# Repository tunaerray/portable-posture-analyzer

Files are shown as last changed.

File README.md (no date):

# Portable Posture & Balance Analyzer

A wearable device designed to monitor back and shoulder posture in real time, alerting the user via vibration and OLED display when poor posture is detected.

> **Work in Progress**  
> PCB design is complete. Firmware development is ongoing.

## Overview

This project is a health and ergonomics-focused embedded system that tracks posture using an IMU sensor. When poor posture is detected, the device triggers a vibration motor and displays a warning on the OLED screen. The system is built around the MSP430G2553 microcontroller.

## Components

- **MPU6050** - 6-axis IMU sensor (accelerometer + gyroscope)
- **Vibration Motor** - Haptic alert for poor posture
- **OLED Display** - Real-time posture score and warning display
- **HC-05 Bluetooth** - Daily report transmission
- **MSP430G2553** - Main microcontroller

## How It Works

1. MPU6050 raw accelerometer and gyroscope data is read over I2C.
2. Angle calculation is performed using `atan2`.
3. A posture score is computed periodically using Timer_A.
4. If poor posture is detected, the vibration motor is activated.
5. The OLED display shows posture status and warning messages.
6. A daily posture report is sent via Bluetooth to a paired device.

## Project Status

- [x] PCB design complete
- [ ] Firmware development in progress
- [ ] Testing and calibration
- [ ] Enclosure design

## Images

### PCB Front

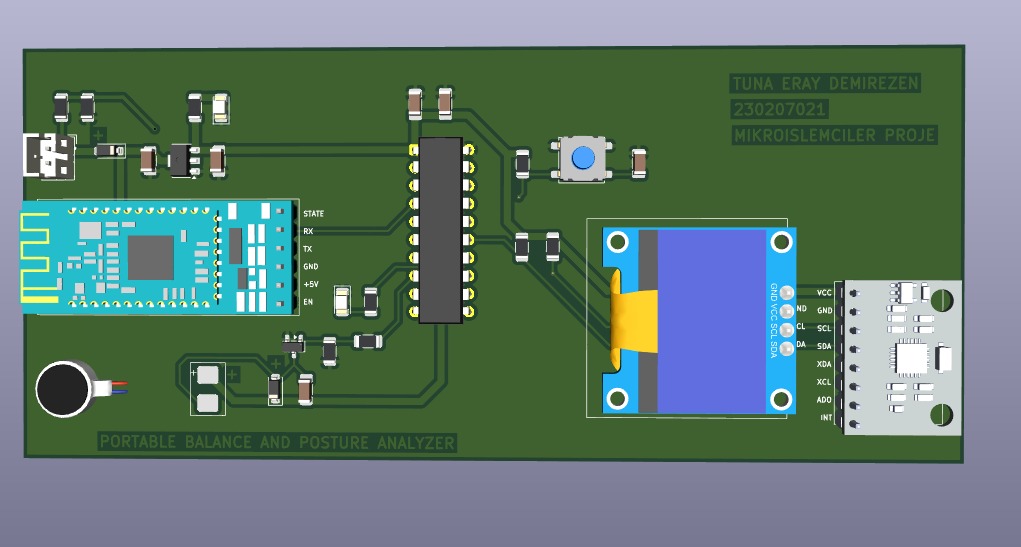
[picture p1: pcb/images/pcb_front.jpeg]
PCB Front


### PCB Back

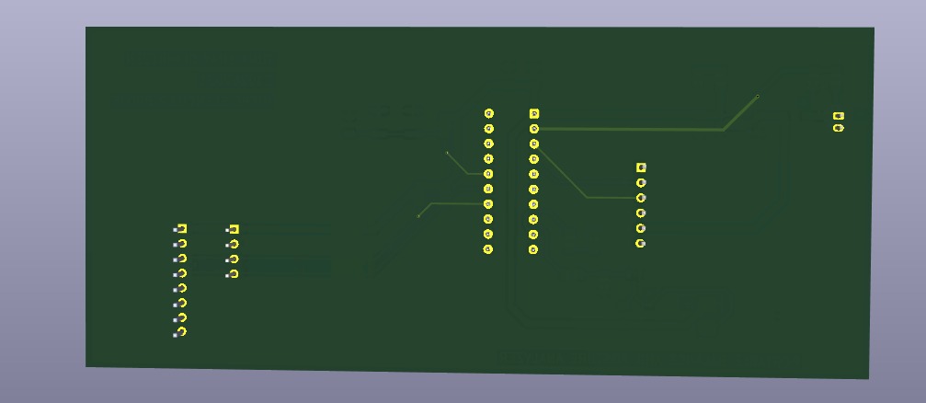
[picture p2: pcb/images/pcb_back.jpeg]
PCB Back


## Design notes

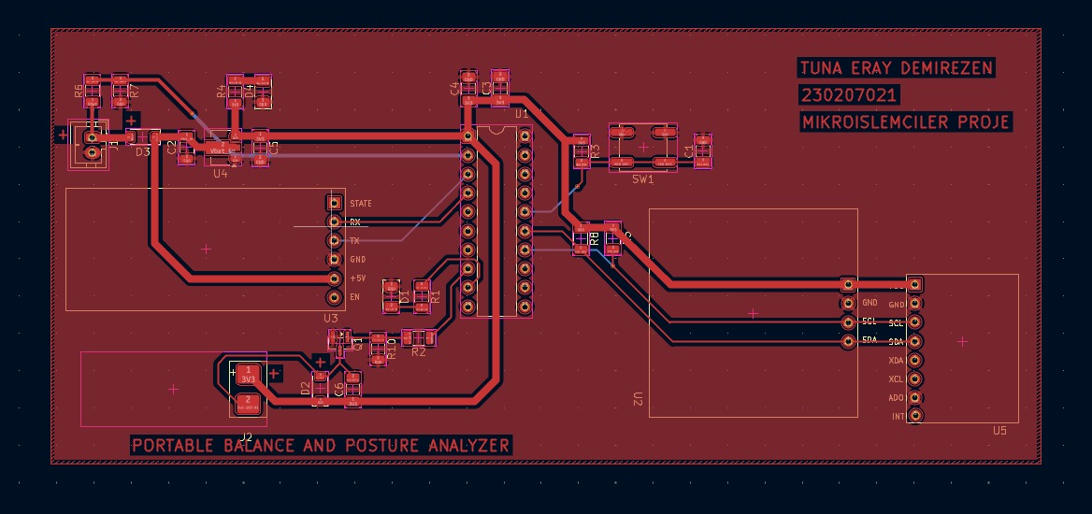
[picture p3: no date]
pcb/images/pcb_layout.jpeg

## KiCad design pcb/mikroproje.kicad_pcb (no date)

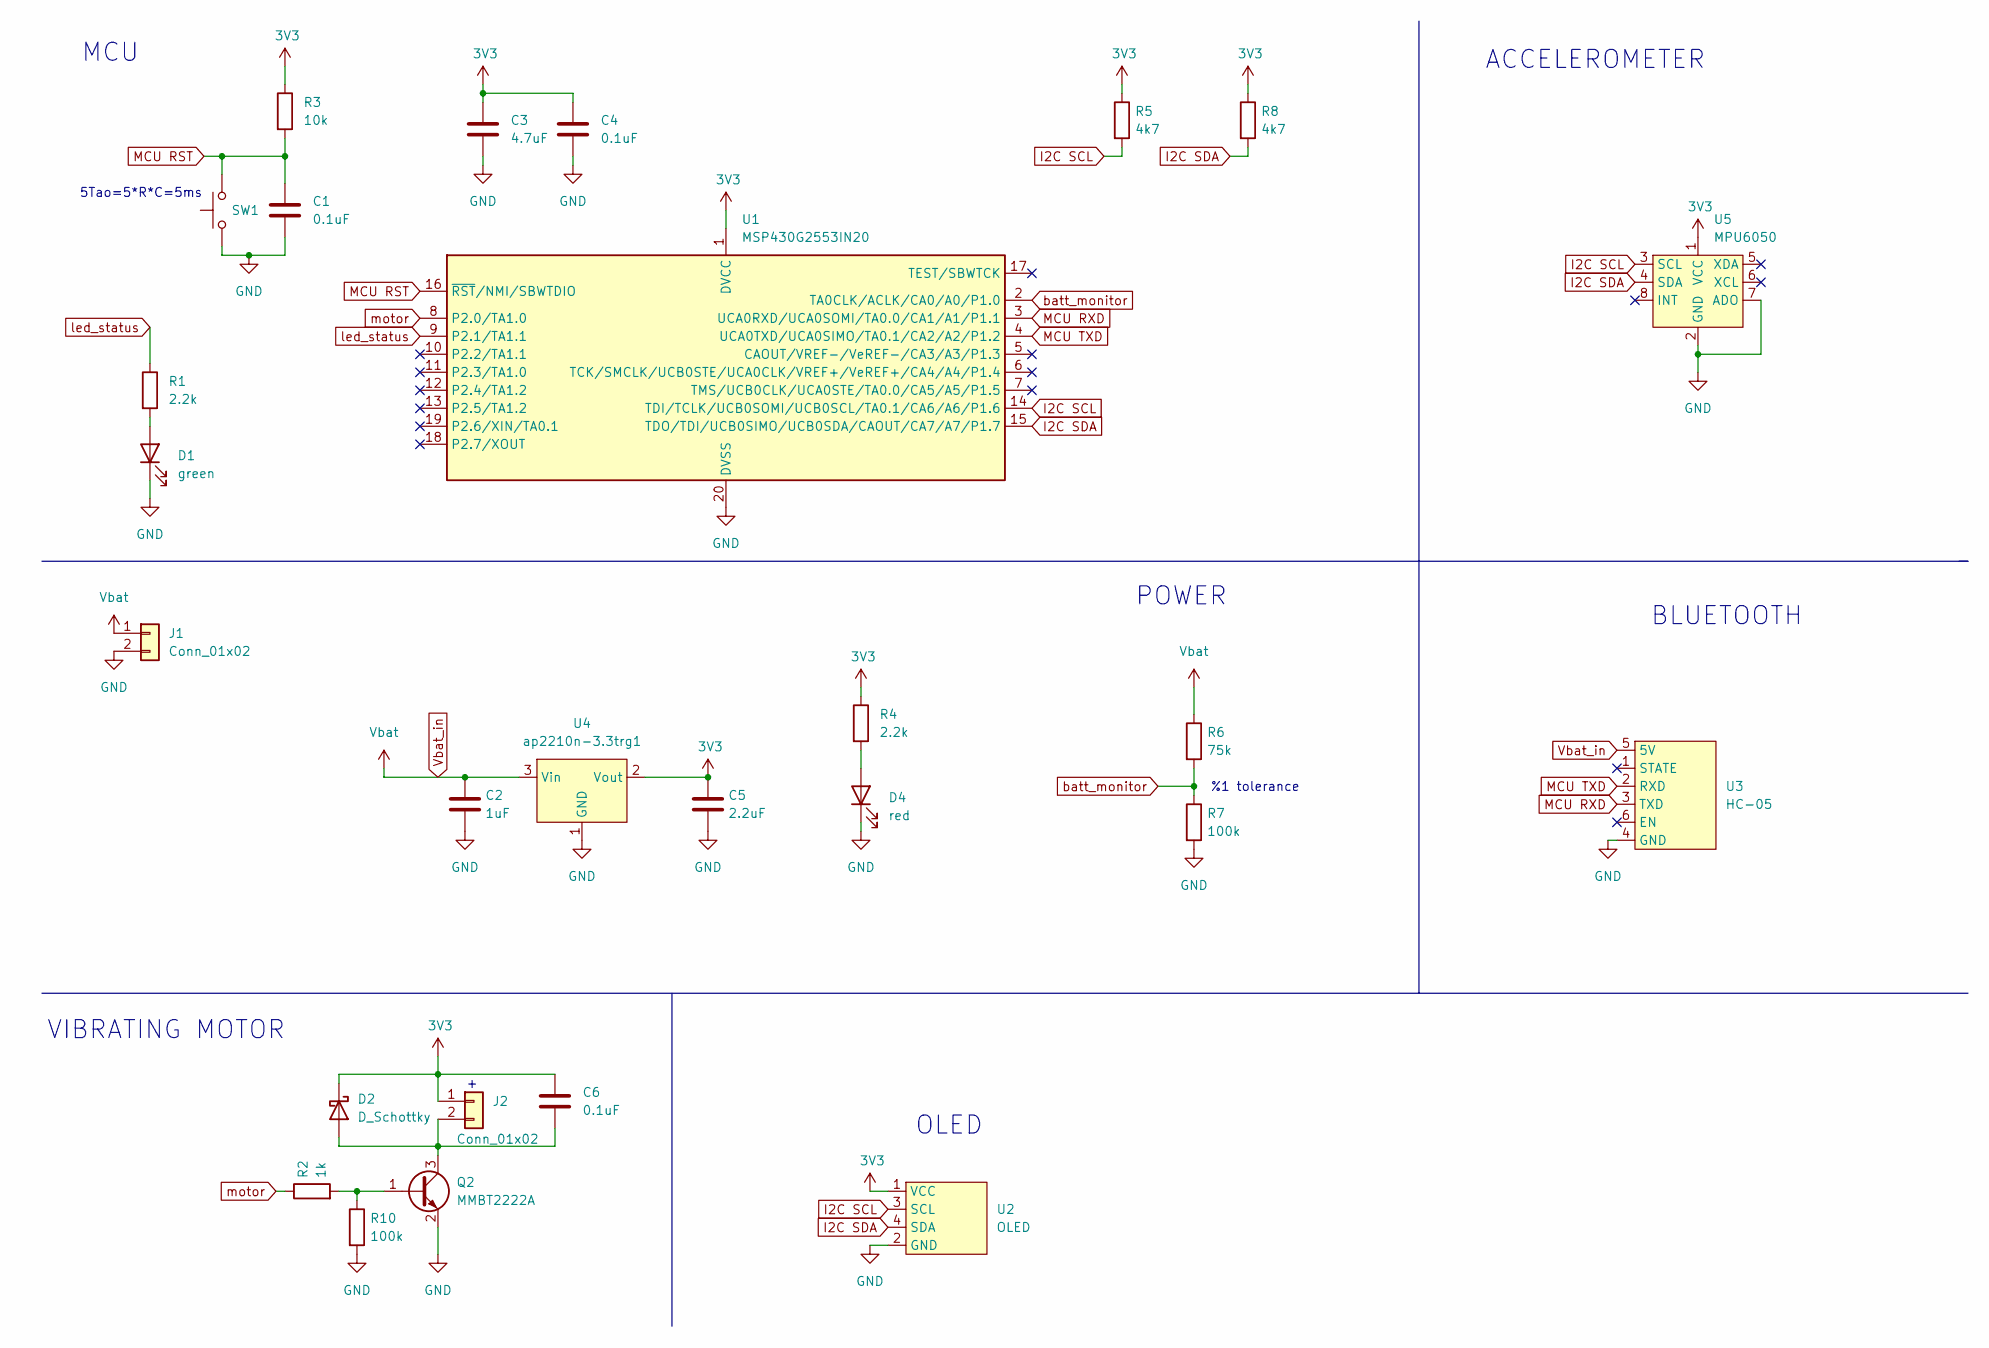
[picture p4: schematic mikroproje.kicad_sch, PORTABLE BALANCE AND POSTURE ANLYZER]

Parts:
C1: 0.1uF; C_1206_3216Metric
C2: 1uF; C_1206_3216Metric
C3: 4.7uF; C_1206_3216Metric_Pad1.33x1.80mm_HandSolder
C4, C6: 0.1uF; C_1206_3216Metric_Pad1.33x1.80mm_HandSolder
C5: 2.2uF; C_1206_3216Metric_Pad1.33x1.80mm_HandSolder
D1: green; LED_1206_3216Metric
D2: D_Schottky; D_SOD-123
D4: red; LED_1206_3216Metric
J1: Conn_01x02; JST_PH_B2B-PH-K_1x02_P2.00mm_Vertical
J2: Conn_01x02; vibrator
Q2: MMBT2222A; SOT-23
R1, R4: 2.2k; R_1206_3216Metric
R2: 1k; R_1206_3216Metric
R3: 10k; R_1206_3216Metric
R5, R8: 4k7; R_1206_3216Metric
R6: 75k; R_1206_3216Metric
R7, R10: 100k; R_1206_3216Metric
SW1: SW_Push; SW_Push_1P1T_NO_CK_KSC7xxJ
U1: MSP430G2553IN20; DIP-20_W7.62mm
U2: OLED
U3: HC-05
U4: ap2210n-3.3trg1; SOT-23-3
U5: MPU6050; MPU6050_Module

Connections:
3V3: C3.1, C4.1, C5.1, C6.1, D2.1 (K), J2.1, R3.1, R4.1, R5.1, R8.1, U1.1 (DVCC), U2.1 (VCC), U4.2 (Vout), U5.1 (VCC)
GND: C1.2, C2.2, C3.2, C4.2, C5.2, D1.1 (K), D4.1 (K), J1.2, Q2.2 (E), R7.2, R10.2, SW1.1, U1.20 (DVSS), U2.2 (GND), U3.4 (GND), U4.1 (GND), U5.2 (GND), U5.7 (ADO)
I2C SCL: R5.2, U1.14 (TDI/TCLK/UCB0SOMI/UCB0SCL/TA0.1/CA6/A6/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), U2.3 (SCL), U5.3 (SCL)
I2C SDA: R8.2, U1.15 (TDO/TDI/UCB0SIMO/UCB0SDA/CAOUT/CA7/A7/P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), U2.4 (SDA), U5.4 (SDA)
MCU RST: C1.1, R3.2, SW1.2, U1.16 (~RST/NMI/SBWTDIO)
MCU RXD: U1.3 (UCA0RXD/UCA0SOMI/TA0.0/CA1/A1/P1.1), U3.3 (TXD)
MCU TXD: U1.4 (UCA0TXD/UCA0SIMO/TA0.1/CA2/A2/P1.2), U3.2 (RXD)
unnamed: D1.2 (A), R1.2
unnamed: C6.2, D2.2 (A), J2.2, Q2.3 (C)
unnamed: D4.2 (A), R4.2
unnamed: Q2.1 (B), R2.2, R10.1
Vbat_in: C2.1, J1.1, R6.1, U3.5 (5V), U4.3 (Vin); also elsewhere on the board
batt_monitor: R6.2, R7.1, U1.2 (TA0CLK/ACLK/CA0/A0/P1.0)
led_status: R1.1, U1.9 (P2.1/TA1.1)
motor: R2.1, U1.8 (P2.0/TA1.0)

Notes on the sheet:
POWER
ACCELEROMETER
VIBRATING MOTOR
MCU
BLUETOOTH
%1 tolerance
OLED
5Tao=5*R*C=5ms

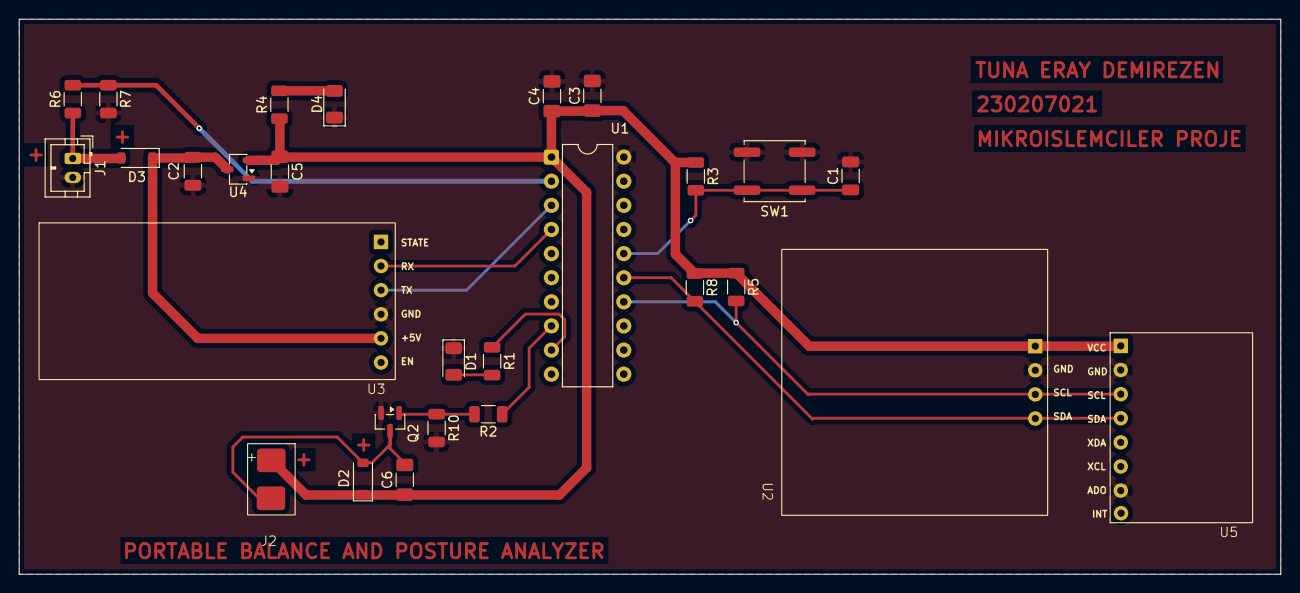
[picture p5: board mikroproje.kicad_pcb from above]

Board: 2 copper layers, 132.8 x 58.5 mm, 28 parts (0 on the bottom side), 15 nets.

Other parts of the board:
D3: D_Schottky; D_SOD-123

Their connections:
Vbat_in: D3.1 (K); also elsewhere on the board

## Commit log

no date Add KiCad PCB project files and update README
    [mikroproje.kicad_pcb, mikroproje.kicad_sch]
no date Revise README with current project status and details
    Updated project details, components, and functionality descriptions in README.md.
no date Remove pin connections details from README
    Removed pin connections section for various components.
no date Update revised portable posture analyzer PCB files
    [mikroproje.kicad_pcb, mikroproje.kicad_sch]
